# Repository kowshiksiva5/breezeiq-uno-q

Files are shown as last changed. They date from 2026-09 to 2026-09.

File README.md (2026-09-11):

# BreezeIQ

**A room-comfort controller that runs entirely on one Arduino UNO Q.** It does not
hold a thermostat setpoint. It computes how the room *feels* — ISO 7730 PMV, which
counts air velocity, so it knows a fan makes 28 °C feel like 25 °C — and then buys
that feeling with the cheapest watt available.

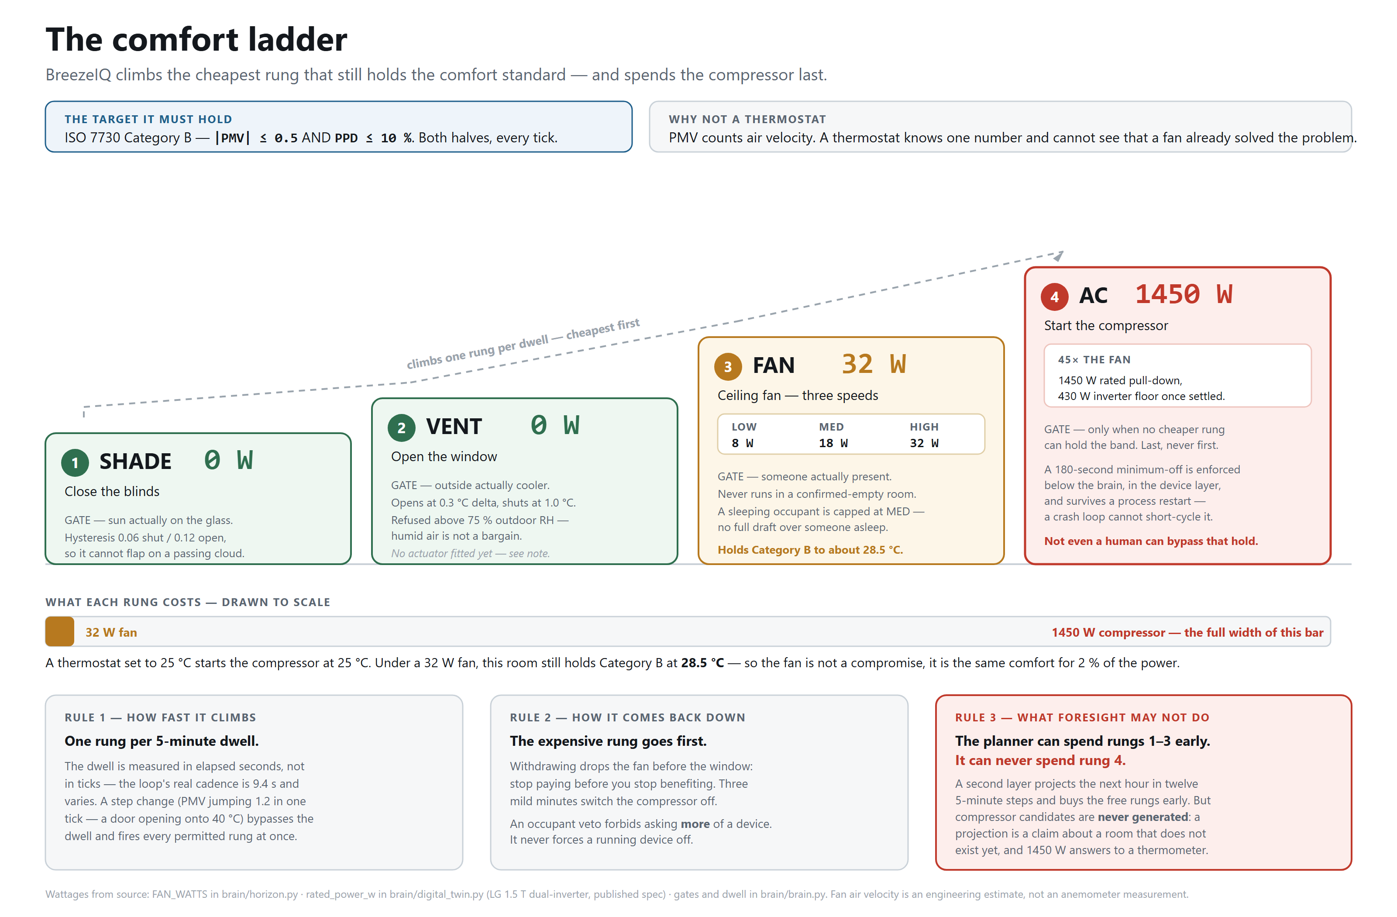
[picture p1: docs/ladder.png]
The comfort ladder: SHADE 0 W, VENT 0 W, FAN 32 W, AC 1450 W, with the gate on each rung


A thermostat set to 25 °C starts a 1450 W compressor at 25 °C. Under a 32 W ceiling
fan the same room still holds ISO Category B comfort at **28.5 °C**. The fan is not a
compromise, it is the same comfort for 2 % of the power — and a setpoint cannot see
that, because air velocity is not one of its inputs.

Each rung fires only if its own gate passes: sun actually on the glass, outdoor air
actually cooler, an occupant actually present. The compressor is spent last, and a
projection is never allowed to start it.

---

## How it works

- **Both halves of the board do real work.** The STM32U585 samples every sensor at
  1 Hz, drives the blinds motor and the LED matrix, and holds a failsafe. The Linux
  MPU runs camera inference, the comfort maths, the policy, SQLite and the web
  console. They talk over Arduino RouterBridge RPC.
- **The STM32 can save the room without Linux.** Ten seconds with no Bridge call and
  the MCU parks the room itself — blinds driven open, failsafe glyph on the matrix —
  armed from boot, re-armed on the next call. A planner that has wedged cannot
  notice it has wedged.
- **One file decides.** `brain/brain.py` is a pure function: reading in, plan out. No
  sockets, no files, no clock. Everything else is transport, so any surprise has
  exactly one suspect.
- **Occupancy is counted on-device and kept nowhere.** A YOLO11s model runs on the
  board's own CPU through ONNX Runtime, fused with the PIR. Frames are counted and
  discarded; one integer is logged. No image ever leaves the board or is stored.
- **An hour-ahead planner spends the free rungs early** — shade and ventilate before
  the heat arrives — but is forbidden from ever starting the compressor, because a
  projection is a claim about a room that does not exist yet.

The board serves its own console over Wi-Fi at `http://breeze.local:8000` — the room
view, a workbench with every raw sensor value, and a log of every command it has
sent and why.

---

## What you need

**₹3 779 (about $45)** of parts if you already own a USB-C hub with power
passthrough, **₹4 629 (about $55)** if you need one too. The board itself came as a
contest award. Prices are Indian street estimates, August 2026.

| Part | Qty | ₹ | What it does |
|---|--:|--:|---|
| **Arduino UNO Q** (4 GB) | 1 | — | Both brains: STM32U585 MCU + Qualcomm Dragonwing Linux MPU |
| **DHT22 / AM2302** | 2 | 250 | Indoor temperature and humidity → the comfort solve. Outdoor → the VENT gate |
| **BH1750** GY-302 lux | 1 | 129 | Sun on the glass → the SHADE gate. I²C, **3.3 V only** |
| **LDR** (GL5528) + 10 kΩ | 1 | 20 | Fallback light sense when lux is unavailable |
| **HC-SR501** PIR | 1 | 90 | Motion → wakes the camera. 3.3 V TTL output, safe |
| **MQ-135** + 10 kΩ/15 kΩ | 1 | 150 | Air-quality trend → evidence for the VENT rung |
| **HLK-LD2410C-P** mmWave radar | 1 | 429 | Presence for a person sitting still. 5 V VCC, 3.3 V logic |
| **UVC webcam**, 720p | 1 | 700 | On-device person count. Must be UVC-class |
| **RS555SF/3162** DC motor | 1 | 50 | Tilts the blinds. 12 V rated, run at 9 V |
| **Bare L298** dual H-bridge IC | 1 | 110 | Drives that motor. *Not* the L298N module — see the traps |
| Motor coupler / bracket | 1 | 40 | Joins the motor to the blind's tilt rod |
| USB-A female breakout | 1 | 60 | Splits the 5 V sensor rail off a spare charger |
| 1000 µF cap + resistor kit | 1 | 50 | Bulk capacitance at the motor, and the two dividers |
| Breadboard 830-pt + jumpers | 1 | 350 | The rig itself |
| 5 mm LED assortment | 1 | 30 | Bench indicators while wiring the driver |
| 9 V supply | 1 | — | Rail C, the motor only |
| USB-C hub **with PD passthrough** | 1 | 850 | The board is USB-C only; this is how the webcam and power coexist |
| White cup + standoff | 1 | 0 | **Radiation shield for the outdoor DHT22 — not optional** |
| Cardboard box + cardstock | 1 | 0 | Scale-model blinds |

Plus, on the network rather than on the board: a **smart ceiling fan** (Atomberg), a
**smart plug** for the AC, and a **smart light**. Any device Home Assistant can reach
works — adding a brand is one file in `act/devices/`.

⚠️ **The USB-C hub must have true PD passthrough.** Without it the board runs off the
hub's own budget and browns out under motor load, dropping the RPC bridge. This is the
one substitution that fails silently.

⚠️ **The radiation shield is not optional.** A DHT22 in direct sun reads 5–10 °C above
true air temperature, which holds the VENT gate false all day and silently disables
free cooling.

---

## Wiring

Arduino UNO Q, **3.3 V logic — no pin on this board is 5 V tolerant.** Pin names are
exactly as silkscreened (no `D` prefix, `~` kept). Direct-wired, no breadboard needed.

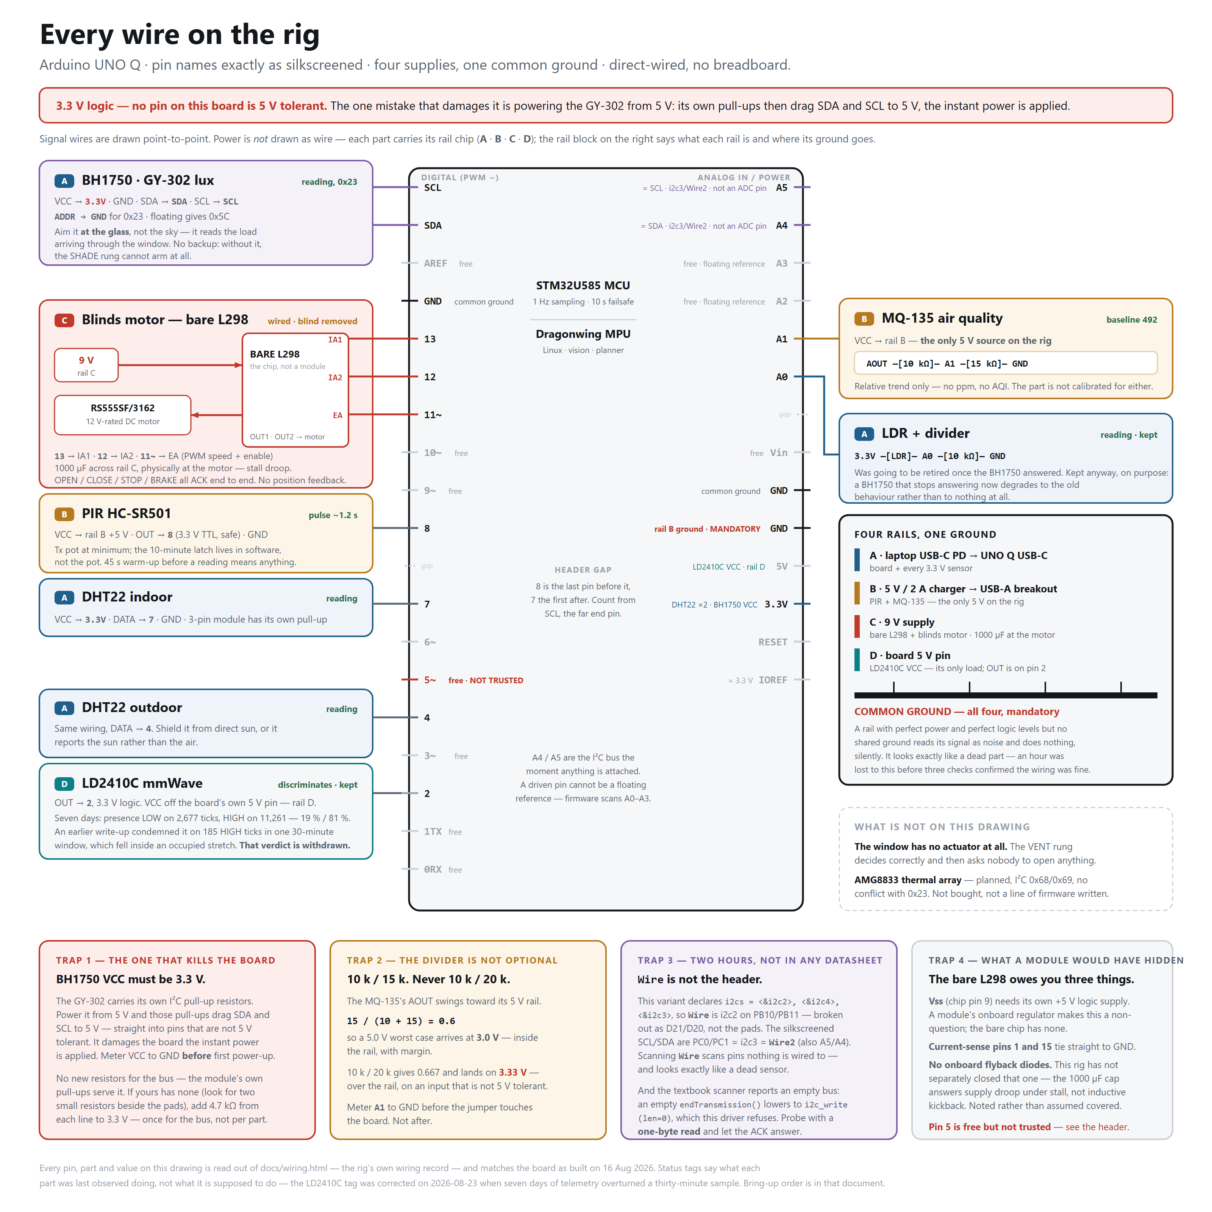
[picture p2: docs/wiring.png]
Every wire on the rig: pin map, four power rails, and the traps


### Every connection

| Part | UNO Q pin | Wiring | Rail |
|---|---|---|---|
| DHT22 indoor | `7` | VCC → `3.3V` · DATA → `7` · GND | A |
| DHT22 outdoor | `4` | VCC → `3.3V` · DATA → `4` · GND. Shield it from the sun | A |
| BH1750 GY-302 | `SDA` `SCL` | VCC → `3.3V` · SDA → `SDA` · SCL → `SCL` · **ADDR → GND** for address `0x23` · GND | A |
| LDR + 10 kΩ | `A0` | `3.3V` —[LDR]— `A0` —[10 kΩ]— GND | A |
| PIR HC-SR501 | `8` | VCC → rail B +5 V · OUT → `8` · GND | B |
| MQ-135 | `A1` | VCC → rail B +5 V · AOUT —[10 kΩ]— `A1` —[15 kΩ]— GND | B |
| LD2410C radar | `2` | VCC → the board's own `5V` pin · OUT → `2` · GND | D |
| Blinds motor, via bare L298 | `13` `12` `11~` | IA1 ← `13` · IA2 ← `12` · EA ← `11~` (PWM speed + enable) · L298 Vs ← 9 V · L298 Vss ← +5 V · sense pins 1 and 15 → GND · motor leads ← OUT1/OUT2 · 1000 µF across rail C at the motor | C |

The fan, the AC and the light are **not** wired to the board. They are reached over
the network. The window has no actuator — the VENT rung decides and asks nobody.

### Four rails, one ground

| Rail | Source | Feeds |
|---|---|---|
| **A** | Laptop or charger USB-C PD → the board's USB-C | The board and every 3.3 V sensor, off its own regulator |
| **B** | 5 V / 2 A charger → USB-A breakout | PIR, MQ-135, and the L298's Vss logic pin. The only 5 V on the rig |
| **C** | 9 V supply | L298 Vs, the blinds motor, the 1000 µF cap |
| **D** | The board's own 5 V pin | The radar only |

**Every rail's ground must land on a board GND pin.** A rail with perfect power and no
shared ground reads its signal as noise and does nothing, silently. It looks exactly
like a dead part — an hour was lost to this before three checks confirmed the wiring
was fine.

### Four traps, all measured on this hardware

1. **BH1750 VCC must be 3.3 V.** The GY-302 carries its own I²C pull-ups, and they sit
   on whatever VCC you feed it. Feed it 5 V and it drags SDA and SCL to 5 V, into pins
   that are not 5 V tolerant, the instant power is applied. Meter VCC to GND *before*
   first power-up.
2. **The MQ-135 divider is not optional, and 10 k / 20 k is wrong.** Its AOUT swings
   toward its 5 V rail. 10 k / 15 k gives 0.6, so a 5.0 V worst case arrives at `A1` as
   3.0 V, inside the rail with margin. 10 k / 20 k gives 0.667 and lands on 3.33 V.
3. **`Wire` is not the header.** On this board the silkscreened SDA/SCL pads are
   PC0/PC1 = i2c3 = **`Wire2`** in firmware. `Wire` is i2c2 on PB10/PB11, broken out as
   D21/D20 — scanning it scans pins nothing is wired to, and looks exactly like a dead
   sensor. Probe with a one-byte read, not an empty `endTransmission()`.
4. **A bare L298 owes you three things** an L298N module would have handled quietly:
   pin 9 `Vss` needs its own +5 V logic supply, current-sense pins 1 and 15 tie
   straight to GND, and there are **no onboard flyback diodes**. The 1000 µF cap
   answers supply droop under stall current; it is not a flyback diode.

### The same rig, drawn for reading

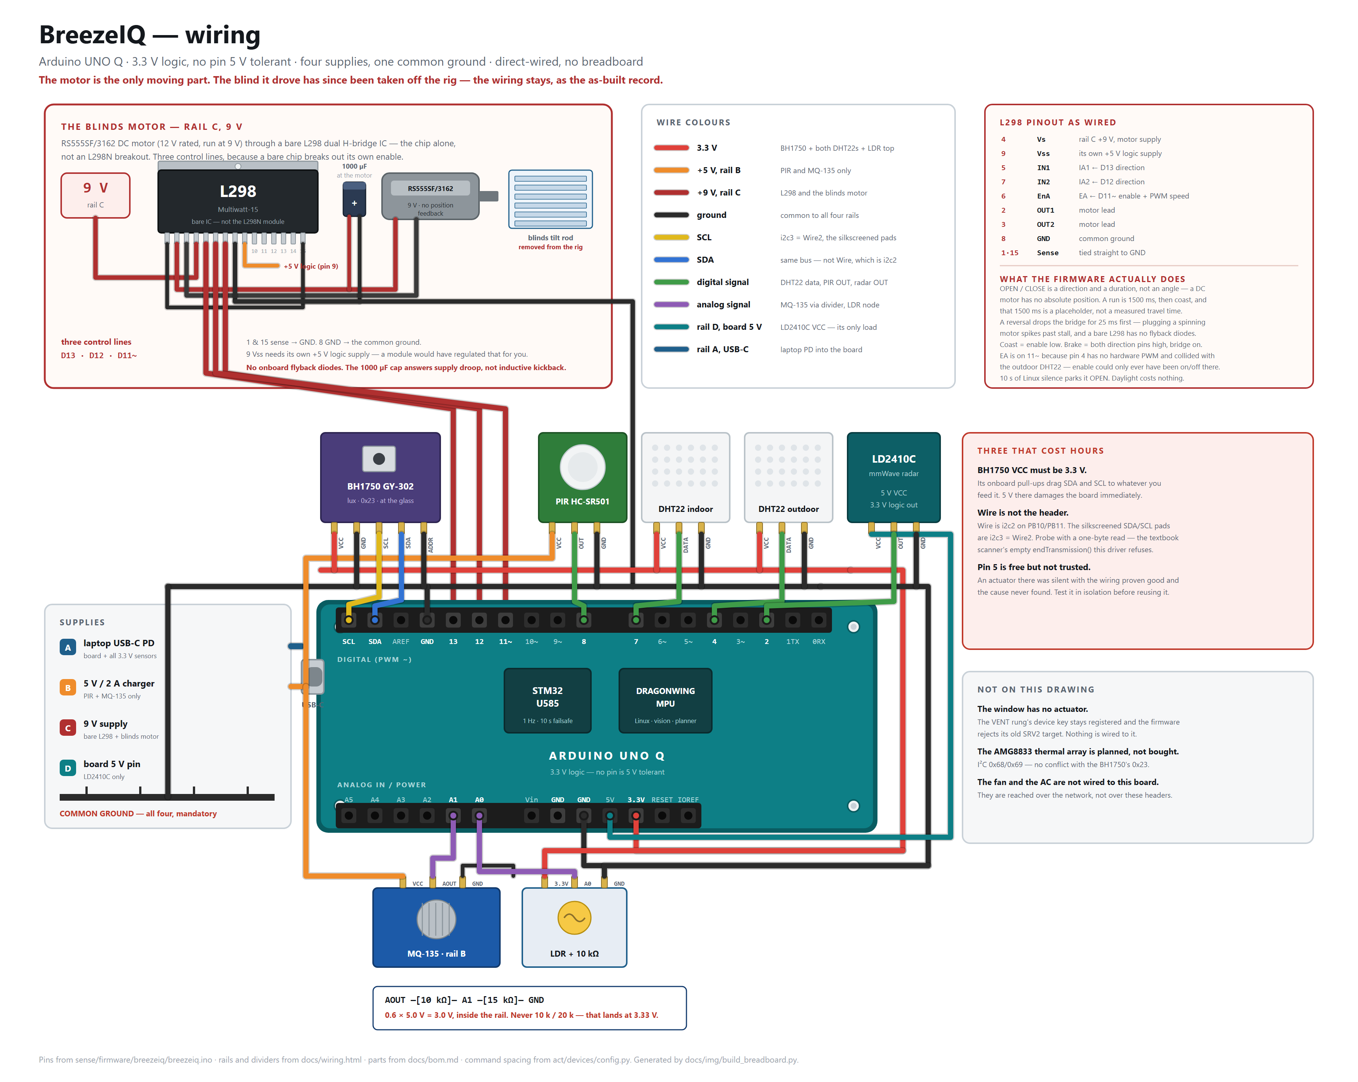
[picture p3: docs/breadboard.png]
Breadboard-style view: every wire drawn to the part it lands on


`docs/breezeiq.fzz` is the same circuit as a **Fritzing** sketch — 15 custom parts,
40 wires, self-contained, no core-parts dependency. Open it once in Fritzing and
re-save before relying on it; it was generated rather than drawn by hand.

### Bring-up order

Sensors first, motor last — brownouts show up there first. Power everything off for
each change. Bring up one sensor at a time and confirm it reads before adding the
next. Wire the motor unloaded, confirm OPEN/CLOSE/STOP, and only then couple it to
the tilt rod.

---

## Build it

### 1 · Try it with no hardware at all

```bash
git clone https://github.com/kowshiksiva5/breezeiq-uno-q.git
cd breezeiq-uno-q
./tools/run.sh setup          # venv + three dependencies
./tools/run.sh demo           # 10 ticks against a simulated room
```

That runs the real control loop — the real comfort solve, the real ladder, the real
telemetry — against a simulated room, and commands nothing. Then:

```bash
./tools/run.sh console        # the web console on http://127.0.0.1:8000
```

### 2 · Flash the STM32 side

```bash
cd firmware
arduino-cli compile --clean --libraries ./libraries -b arduino:zephyr:unoq breezeiq
arduino-cli upload -b arduino:zephyr:unoq -p /dev/cu.usbmodem<yours> breezeiq
```

**Always `--clean`.** Uploads have reported success without flashing on this board;
every sketch prints `BUILD=n` on boot, so check that it says what you just flashed.

### 3 · Put the board on Wi-Fi, then deploy

```bash
./tools/run.sh wifi <your-ssid>     # over USB; the password is asked for, never stored
./tools/run.sh deploy               # pushes the app to the board over SSH
```

`deploy.sh` assembles the App Lab app — the sketch, the Python, the manifest —
stages it on the board, import-checks it there, and only then swaps it in. Press
**Run** in App Lab, or let the boot hook start it after a power cut. The console is
then at `http://breeze.local:8000` from any phone on the same Wi-Fi.

⚠️ **The UNO Q has one USB controller.** A USB-C *data* cable puts the board in
peripheral mode — that is what serves `adb`, and it is also what holds the USB power
regulator disabled, so no USB camera can enumerate. ADB and the camera are mutually
exclusive. Use the cable for first bring-up, then work over Wi-Fi.

### 4 · Connect the real devices

```bash
cp .env.example .env && chmod 600 .env      # then fill it in
```

Home Assistant runs on the board as a protocol adapter and holds no automations of
its own — `act/infra/docker-compose.yml` is the container that runs here. It speaks
Tuya so BreezeIQ never has to. The Atomberg fan is reached through its own API, with
state read free off LAN beacons to stay under the vendor's 100-calls-per-day limit.

**Nothing switches anything real until two gates are set**, both in `.env`:
`BREEZEIQ_LIVE=1` and `BREEZEIQ_SAFETY_VALIDATED=1`. Dry-run is the default on
purpose — a fresh clone must not be able to turn someone's AC on. Set the second gate
only after dry-run output, entity mapping, independent readback, rate limits and the
compressor's minimum-off hold have all been checked.

```bash
./tools/run.sh control --dry-run    # decide against live sensors, touch nothing
./tools/run.sh devices health       # what the device layer can see
./tools/run.sh control --live       # command real devices
```

---

## What is in here

| Path | What |
|---|---|
| `firmware/breezeiq/breezeiq.ino` | The MCU sketch: 1 Hz sampling, Bridge RPC, motor grammar, the 10 s failsafe |
| `firmware/libraries/BreezeIQ/` | One small module per sensor, shared by the sketch |
| `brain/brain.py` | **The only thing that decides anything.** The ladder, as a pure function |
| `brain/comfort.py` | ISO 7730 PMV and PPD |
| `brain/horizon.py` | The hour-ahead planner |
| `brain/digital_twin.py` | The AC response model |
| `brain/loop.py` | Read → decide → command → log. Translates; decides nothing |
| `brain/telemetry.py` | Every tick to SQLite |
| `brain/dashboard.py` · `console.py` | The API, and the pages rendered over it. Stdlib only |
| `sense/reader/` | Bridge RPC, serial and simulated sensor sources behind one interface |
| `sense/vision/` | On-device person counting, and the policy for when to look |
| `act/devices/` | Home Assistant, Atomberg, the board's own motor, simulated |
| `app/` | App Lab packaging |
| `tools/` | `run.sh` for everything local, `deploy.sh` for the board |
| `docs/` | The wiring drawings and the Fritzing sketch |

Adding a device brand is one file: subclass `DeviceBackend`, register it, done.
Nothing upstream changes — the Atomberg fan proved it, and the ladder never learned a
word of its protocol.

---

## Known limits, stated plainly

- **The window has no actuator.** The VENT rung decides correctly and then asks
  nobody to open anything. Three of the four rungs move real hardware.
- **The "weather" is the board's own outdoor sensor**, not a fetched forecast. That
  is deliberate — the appliance has to work with no internet — but it means the
  horizon is a projection from local physics, not a meteorological one.
- **The energy comparisons are simulated**, from the repository's own room model,
  and are labelled that way wherever they appear.
- **The console trusts its LAN.** There is no login. Keep the board behind your
  router and do not expose port 8000 to the internet.

---

## License

MIT — see [`LICENSE`](LICENSE). Built on an Arduino UNO Q supplied as a contest award
for *Invent the Future with Arduino UNO Q & App Lab* (Hackster.io).

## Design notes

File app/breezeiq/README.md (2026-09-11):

# BreezeIQ — the App Lab app

Passive-first room comfort on the Arduino UNO Q. Both halves of the board are used:

- **STM32** (`sketch/`) — sensors, the blinds motor, the LED matrix, and a failsafe:
  10 s without a Bridge call and the MCU drives the blinds open at full speed and
  lights a matrix glyph on its own, re-arming when calls resume.
- **Linux MPU** (`python/`) — PMV comfort maths, the passive-first ladder, device
  control, and the console on `:8000`.

## Run

Press **Run** in App Lab. Then open `http://<board-ip>:8000` from any phone on the
same Wi-Fi. `tools/deploy.sh` also installs a boot hook, so the app comes back on
its own after a power cut with no laptop present.

Dry-run by default. Real commands require both `BREEZEIQ_LIVE=1` and
`BREEZEIQ_SAFETY_VALIDATED=1` in the board's own `.env`, which `deploy.sh` carries
forward and never uploads. Credentials live only there:

    HA_URL, HA_TOKEN                        Tuya devices via Home Assistant
    ATOMBERG_API_KEY, ATOMBERG_REFRESH_TOKEN, ATOMBERG_FAN_ID

Home Assistant runs at `http://127.0.0.1:8123` on the board and holds device
integrations only. BreezeIQ owns policy and manual-override authority.

## The one rule

`brain.py` is the only thing that makes a comfort decision, and it is a pure
function. Everything else — sensors, devices, dashboard — is transport. Keep it that
way and any surprise has exactly one suspect.

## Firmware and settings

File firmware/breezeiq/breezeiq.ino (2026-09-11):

/*
 * BreezeIQ wiring verifier. One question per input: is it connected, and if
 * not, what is wrong. Emits a key=value line per second for the dashboard and
 * lights one matrix column per channel that produced a usable reading:
 *
 *   col 0 = DHT22 indoor   col 1 = DHT22 outdoor   col 2 = LDR
 *   col 3 = PIR            col 4 = MQ-135
 *
 * It also holds the one promise Linux cannot keep for itself: if the Linux
 * side stops calling over the Bridge, this sketch parks the blinds motor in
 * its safe position on its own. See the failsafe section below.
 *
 * Four RPCs are exposed: breezeiq/read (telemetry), breezeiq/cmd (motor and
 * the display), breezeiq/display (the display alone), and breezeiq/radar_tune
 * (a bench-only hex relay onto the radar's serial port; the deployed loop never
 * calls it). Every one of them is also proof Linux is alive, so every one of
 * them re-arms the failsafe -- as does every complete serial command line.
 */

#include <DHT.h>
#include <Wire.h>
#include "Arduino_LED_Matrix.h"
#include "Arduino_RouterBridge.h"

// Adafruit DHT 1.4.7 calls these Arduino API functions from its timing guard,
// but Arduino UNO Q Zephyr core 0.90.0 declares them without exporting an
// implementation to App Lab sketches. Interrupt masking also stalls the UNO Q
// bridge transport. Keep the library's proven pulse decoder and map its guard
// to Zephyr's scheduler lock. This prevents thread preemption during the pulse
// train while leaving RouterBridge and other hardware interrupts operational.
#if defined(ARDUINO_ARCH_ZEPHYR)
extern "C" void k_sched_lock(void);
extern "C" void k_sched_unlock(void);
void noInterrupts() { k_sched_lock(); }
void interrupts() { k_sched_unlock(); }
#endif

constexpr int PIN_DHT_INDOOR  = 7;    // "7"
constexpr int PIN_DHT_OUTDOOR = 4;    // "4"
constexpr int PIN_PIR         = 8;    // "8"
constexpr int PIN_LDR         = A0;   // "A0"
constexpr int PIN_MQ135       = A1;   // "A1"
constexpr int PIN_RADAR       = 2;    // "2"  LD2410C OUT, 3.3 V logic -- back to its physical
                                       // wiring. The D2->D13 move was a diagnostic (isolating
                                       // pin vs. sensor); the sensor itself is the dead part
                                       // either way -- see the README's wiring table. Kept wired and read
                                       // rather than removed: it's still physically on the rig.

// BH1750 on the I²C header pins, which on this board means Wire2 and not Wire.
// The variant declares i2cs = <&i2c2>, <&i2c4>, <&i2c3>, so Wire is i2c2 on
// PB10/PB11 (broken out as D21/D20), Wire1 is i2c4 (the camera's bus, left
// alone), and only Wire2 is i2c3 on PC0/PC1 — the pads silkscreened SCL and
// SDA, which are also A5 and A4. Scanning Wire finds an empty bus and looks
// exactly like a dead sensor, which cost an evening; the bus is named once
// here so it cannot be assumed again.
//
// Register-level because the whole part is three bytes: a mode, a wait, and a
// big-endian count that is lux times 1.2. Both addresses are probed at run
// time rather than one being assumed — see bh1750Begin().
// All three, because "which bus" and "is it wired" are different questions and
// only a scan of every bus separates them. Wire is i2c2 (PB10/PB11 = D21/D20),
// Wire1 is i2c4, Wire2 is i2c3 (PC0/PC1 = the SCL/SDA pads, also A5/A4).
arduino::ZephyrI2C *const I2C_BUSES[] = {&Wire, &Wire1, &Wire2};
constexpr int I2C_BUS_COUNT = sizeof(I2C_BUSES) / sizeof(I2C_BUSES[0]);
constexpr uint8_t  BH1750_ADDR_LOW   = 0x23;   // ADDR tied low / floating
constexpr uint8_t  BH1750_ADDR_HIGH  = 0x5C;   // ADDR tied to 3.3 V
constexpr uint8_t  BH1750_CONT_HIGH = 0x10;   // continuous, 1 lx, ~120 ms
constexpr float    BH1750_DIVISOR   = 1.2f;
constexpr float    BH1750_MAX_LUX   = 54612.0f;

constexpr int ADC_MAX = 4095;         // 12-bit
// How far off either rail a count has to sit before it is worth anything. The
// host's reader uses the same 15; keep them equal or the two disagree about
// which channels are alive.
constexpr int ADC_RAIL_MARGIN = 15;

constexpr unsigned long SAMPLE_PERIOD_MS = 1000;
unsigned long nextSampleAt = 0;

// ── live tuning state ───────────────────────────────────────────────────
// hwcheck feeds the dashboard, so the tuning numbers you would otherwise get
// from t1..t5 are computed here too. Cover the LDR / wave at the PIR and the
// constants appear on the page — no reflashing between tune and observe.
int  ldrMin = ADC_MAX, ldrMax = 0;         // -> LDR_RAW_DARK / LDR_RAW_SUN
int  dhtOk = 0, dhtTry = 0;                // DHT read success rate
float dhtMinC = 1e9, dhtMaxC = -1e9;       // DHT noise band when idle
unsigned long pirEvents = 0, pirHighSince = 0, pirLastPulse = 0;
bool  pirPrev = false;
float mqR0k = NAN;                         // clean-air baseline

// Calibrated 2026-08-09 against a trusted 25.0 C room reference after the
// firmware restart. Twelve live samples averaged 27.06 C indoors and 27.00 C
// outdoors. Keep the raw values in telemetry as proof of the sensor output.
constexpr float TEMP_REFERENCE_C  = 25.0f;
constexpr float TEMP_OFFSET_IN_C  = -2.1f;
constexpr float TEMP_OFFSET_OUT_C = -2.0f;

DHT dhtIndoor(PIN_DHT_INDOOR, DHT22);
DHT dhtOutdoor(PIN_DHT_OUTDOOR, DHT22);
ArduinoLEDMatrix matrix;
uint8_t frame[8 * 13];
String latestSnapshot = "";

enum Status : uint8_t { ST_OK, ST_NO_RESPONSE };

// Use the underlying byte in this public signature because App Lab's Arduino
// preprocessor injects function prototypes above sketch-defined enum types.
const char *statusName(uint8_t s) {
  switch (s) {
    case ST_OK:          return "OK";
    case ST_NO_RESPONSE: return "NO_RESPONSE";
    default:             return "NO_RESPONSE";
  }
}

// No connectivity heuristic here any more. Three of them were tried (internal
// pull-up/pull-down, absolute level, single-HIGH latch) and a floating CMOS
// input defeated all three — the old code reported a confident OK on a pin with
// nothing attached, and the dashboard turned that into a fake air-quality
// reading. The board now reports the raw count and nothing else; deciding what
// is connected is done host-side by comparing against A0, A2 and A3, which are
// known to have nothing on them. A4/A5 used to be in that set and no longer
// qualify: they are the I²C bus now, and a driven pin is not a reference.
void readAnalogStable(int pin, int &average, int &span) {
  // Discard the first conversion after switching ADC channels, then measure a
  // short burst. A driven divider stays tight; a loose/floating node wanders.
  (void)analogRead(pin);
  delayMicroseconds(200);
  long total = 0;
  int low = ADC_MAX, high = 0;
  for (int i = 0; i < 8; i++) {
    int value = analogRead(pin);
    total += value;
    if (value < low) low = value;
    if (value > high) high = value;
    delayMicroseconds(100);
  }
  average = (int)(total / 8);
  span = high - low;
}

// The PIR reports its raw level. Whether that level means "a PIR is attached"
// is not something this board can decide — see the note above.
bool readPir(int pin) {
  pinMode(pin, INPUT);
  return digitalRead(pin) == HIGH;
}

// The radar's OUT is a level, exactly like the PIR's, and carries the same
// caveat: this board reports what the pin says and does not claim a part is
// attached. What differs is upstream — OUT stays HIGH for a person sitting
// still, which is the whole reason it is here beside a PIR that will not.
//
// The level alone is not enough to tell a working radar from a dead one: a
// stuck pin and a genuinely occupied room read identically at any single
// instant. What separates them is TIME — a live sensor changes its mind
// eventually, a dead one never does. So the two figures below ride along
// with the level, and they are what actually diagnosed this part: edges
// counts transitions since boot, held_ms is how long the current level has
// stood. Zero edges over hours is not presence, it is a fault.
unsigned long radarEdges = 0;
unsigned long radarHeldSince = 0;
int radarLastLevel = -1;

bool readRadar(int pin) {
  pinMode(pin, INPUT);
  bool level = digitalRead(pin) == HIGH;
  if (radarLastLevel != (int)level) {
    if (radarLastLevel != -1) radarEdges++;   // boot is not an edge
    radarLastLevel = (int)level;
    radarHeldSince = millis();
  }
  return level;
}

// Which address answered, or 0. Kept as state because the useful question is
// not "did this read fail" but "is the part on the bus at all", and those need
// different fixes — a swapped SDA/SCL pair versus a floating ADDR pin.
uint8_t bh1750Addr = 0;
int     bh1750Bus  = -1;
int     i2cDevices = -1;
int     busDevices[3] = {-1, -1, -1};
bool    sdaPullup = false, sclPullup = false;   // boot-time only, see setup()
int     sdaLevel = -1, sclLevel = -1;           // the same pins via the ADC

// Probes with a one-byte read, not an empty write. endTransmission() with
// nothing buffered lowers to i2c_write(len=0), which this STM32 driver refuses
// outright — so the textbook Arduino scan reports an empty bus whatever is on
// it. A read puts a real START and address on the wire and the ACK is the
// answer. Non-destructive: nothing is written to a part we have not identified.
bool i2cPresent(arduino::ZephyrI2C *bus, uint8_t addr) {
  return bus->requestFrom((int)addr, 1) == 1;
}

// Try both BH1750 addresses rather than only the wired one. ADDR floating
// instead of tied is the single most likely wiring slip on this part, and it
// presents as total silence at 0x23 while the sensor sits happily at 0x5C.
// Re-runs while unfound, so plugging it in does not need a reboot.
void bh1750Begin() {
  bh1750Addr = 0;
  bh1750Bus = -1;
  for (int b = 0; b < I2C_BUS_COUNT && !bh1750Addr; b++) {
    if (i2cPresent(I2C_BUSES[b], BH1750_ADDR_LOW))       bh1750Addr = BH1750_ADDR_LOW;
    else if (i2cPresent(I2C_BUSES[b], BH1750_ADDR_HIGH)) bh1750Addr = BH1750_ADDR_HIGH;
    if (bh1750Addr) bh1750Bus = b;
  }
  if (bh1750Bus < 0) return;
  // A one-byte write, which is a real transfer and therefore actually lands.
  arduino::ZephyrI2C *bus = I2C_BUSES[bh1750Bus];
  bus->beginTransmission(bh1750Addr);
  bus->write(BH1750_CONT_HIGH);
  if (bus->endTransmission() != 0) { bh1750Addr = 0; bh1750Bus = -1; }
}

// Counts everything that ACKs. Distinguishes "the bus is dead" from "the bus
// works and this part is not on it" — one is wiring to the board, the other is
// wiring to the module, and guessing between them wastes an evening.
int i2cScan() {
  int found = 0;
  for (int b = 0; b < I2C_BUS_COUNT; b++) {
    busDevices[b] = 0;
    for (uint8_t addr = 0x08; addr < 0x78; addr++)
      if (i2cPresent(I2C_BUSES[b], addr)) busDevices[b]++;
    found += busDevices[b];
  }
  return found;
}

// Negative means "no answer", which is a different fact from 0 lux and has to
// survive as one — a dark room and an absent sensor must never serialise the
// same. An I²C part either ACKs or it does not, so unlike the ADC channels
// this one can honestly report its own presence.
//
// Every OTHER channel on this board is a burst average — readAnalogStable()
// takes 8 samples specifically because "a driven divider stays tight; a
// loose/floating node wanders." The BH1750's first live minutes proved the
// same is true of it: lux swung 24 to 127 tick to tick on a room the LDR saw
// as perfectly steady throughout, which is enough on its own to flap the fused
// dark/normal verdict.
//
// Smoothed across TICKS rather than as a burst inside one. A burst needs the
// part's ~120 ms conversion time between samples to get fresh conversions
// rather than the same register three times, and spending 60+ ms blocked here
// would starve serviceIo(), which has to keep pumping the motor's run timer
// and the command channel — the sensor read sits mid-tick, where a timed
// drive may be in progress. The
// sampler already runs at 1 Hz, so a short running mean over consecutive
// ticks costs nothing and blocks nobody.
//
// A failed transfer resets the window instead of averaging across the gap: a
// part that dropped off the bus and came back is not the same reading it was
// before, and a missing sensor must stay unambiguous.
constexpr int BH1750_WINDOW = 4;
float bh1750Recent[BH1750_WINDOW];
int   bh1750Count = 0;

float readBh1750() {
  if (!bh1750Addr || bh1750Bus < 0) { bh1750Count = 0; return -1.0f; }
  arduino::ZephyrI2C *bus = I2C_BUSES[bh1750Bus];
  if (bus->requestFrom((int)bh1750Addr, 2) != 2) {
    bh1750Addr = 0; bh1750Count = 0; return -1.0f;
  }
  uint16_t raw = ((uint16_t)bus->read() << 8) | bus->read();
  float lux = raw / BH1750_DIVISOR;
  if (lux > BH1750_MAX_LUX) lux = BH1750_MAX_LUX;

  if (bh1750Count < BH1750_WINDOW) {
    bh1750Recent[bh1750Count++] = lux;
  } else {
    for (int i = 1; i < BH1750_WINDOW; i++) bh1750Recent[i - 1] = bh1750Recent[i];
    bh1750Recent[BH1750_WINDOW - 1] = lux;
  }
  float total = 0;
  for (int i = 0; i < bh1750Count; i++) total += bh1750Recent[i];
  return total / bh1750Count;
}

// Three tenants on one 8x13 panel, and they do not overlap by construction:
//
//   rows 1-6, x = 1,3,5,7,9   five sensor-health columns (this board's own)
//   row  7,   x = 0..8        people count, one pixel each (from Linux)
//   rows 0-7, x = 10          occupancy mode glyph        (from Linux)
//   rows 0-7, x = 11..12      failsafe                    (this board's own)
constexpr int MATRIX_COLS = 13;
constexpr int MATRIX_ROWS = 8;
constexpr int FAILSAFE_GLYPH_COL = 11;   // 11..12, clear of every other tenant
constexpr int OCCUPANCY_GLYPH_COL = 10;
constexpr int PEOPLE_BAR_ROW = 7;
constexpr int PEOPLE_MAX = 9;
constexpr int OCCUPANCY_MODES = 4;

// One bit per row, LSB = row 0. Four shapes nobody has to decode: nothing, a
// dot, a solid column, a dashed column.
constexpr uint8_t OCCUPANCY_GLYPH[OCCUPANCY_MODES] = {
  0x00,   // 0 EMPTY    — a dark column, because nobody is here
  0x18,   // 1 OCCUPIED — a dot at the middle
  0xFF,   // 2 CROWDED  — solid
  0x55,   // 3 ASLEEP   — dashed
};

bool channelOk[5] = {false, false, false, false, false};
bool failsafeActive = false;
int  occupancyMode = -1;      // -1 = Linux has not said yet, so nothing drawn
int  peopleCount = 0;
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
void loop() {
  // The library rate-limits internally (a DHT22 samples at 0.5 Hz) and returns
  // its cached frame in between, so calling once a second is fine.
  float tInRaw  = dhtIndoor.readTemperature(),  hIn  = dhtIndoor.readHumidity();
  float tOutRaw = dhtOutdoor.readTemperature(), hOut = dhtOutdoor.readHumidity();

  Status sIn  = isnan(tInRaw)  ? ST_NO_RESPONSE : ST_OK;
  Status sOut = isnan(tOutRaw) ? ST_NO_RESPONSE : ST_OK;
  float tIn  = isnan(tInRaw)  ? tInRaw  : tInRaw  + TEMP_OFFSET_IN_C;
  float tOut = isnan(tOutRaw) ? tOutRaw : tOutRaw + TEMP_OFFSET_OUT_C;

  // A4 and A5 are the I²C bus. Sampling them as ADC channels was harmless
  // while nothing was attached — they were the reference pins the host uses to
  // recognise a floating input — but a driven bus reads like a live sensor and
  // would turn that reference into a lie. A0 replaces them once the LDR goes.
  const int adcPins[4] = {A0, A1, A2, A3};
  int adcValue[4], adcSpan[4];
  for (int i = 0; i < 4; i++)
    readAnalogStable(adcPins[i], adcValue[i], adcSpan[i]);

  int   ldr    = adcValue[0];
  int   mq     = adcValue[1];
  bool  motion = readPir(PIN_PIR);
  bool  radar  = readRadar(PIN_RADAR);
  if (!bh1750Addr) { i2cDevices = i2cScan(); bh1750Begin(); }
  float lux    = readBh1750();

  // ── tuning accumulators ───────────────────────────────────────────────
  // These are what t1..t5 would print. Computed here so you can tune while
  // watching the dashboard, instead of reflashing between tune and observe.
  dhtTry++;
  if (!isnan(tIn)) {
    dhtOk++;
    if (tIn < dhtMinC) dhtMinC = tIn;
    if (tIn > dhtMaxC) dhtMaxC = tIn;
  }
  // Only track the LDR range once the pin is genuinely driven. A floating or
  // half-built divider would otherwise pin dark at 0 and sun at 4095 and the
  // captured constants would be pure noise.
  if (ldr > ADC_RAIL_MARGIN && ldr < ADC_MAX - ADC_RAIL_MARGIN
      && adcSpan[0] < 300) {
    if (ldr < ldrMin) ldrMin = ldr;
    if (ldr > ldrMax) ldrMax = ldr;
  }
  if (motion && !pirPrev) { pirHighSince = millis(); pirEvents++; }
  if (!motion && pirPrev && pirHighSince) pirLastPulse = millis() - pirHighSince;
  pirPrev = motion;

  // MQ baseline = cleanest air seen = highest sensor resistance.
  if (mq > ADC_RAIL_MARGIN && mq < ADC_MAX - ADC_RAIL_MARGIN) {
    float vOut = ((mq / 4095.0f) * 3.3f) / 0.6f;
    vOut = vOut > 4.99f ? 4.99f : (vOut < 0.01f ? 0.01f : vOut);
    float rs = (5.0f - vOut) / vOut * 10.0f;
    if (isnan(mqR0k) || rs > mqR0k) mqR0k = rs;
  }

  // A lit column means "this channel produced a usable reading just now", and
  // nothing stronger. The DHTs prove themselves by answering; the PIR shows
  // its live level; the two ADC channels light when they sit off both rails,
  // which is the strongest honest statement this board can make about an
  // analogue pin — see the note above readAnalogStable() for why "connected"
  // is a host-side verdict. An unlit LDR column is real information, not a
  // placeholder: it means that pin is pinned to a rail right now.
  channelOk[0] = sIn == ST_OK;
  channelOk[1] = sOut == ST_OK;
  channelOk[2] = ldr > ADC_RAIL_MARGIN && ldr < ADC_MAX - ADC_RAIL_MARGIN;
  channelOk[3] = motion;
  channelOk[4] = mq > ADC_RAIL_MARGIN && mq < ADC_MAX - ADC_RAIL_MARGIN;
  drawMatrix();

  // Rails cannot be measured from the MCU, only inferred from a sensor that
  // answers. A DHT that replies proves its own 3.3 V. The analogue heuristics
  // cannot prove anything, so they are not allowed to claim a rail.
  const char *rail33 = (sIn == ST_OK || sOut == ST_OK) ? "PROVEN" : "UNPROVEN";
  const char *rail5  = "UNPROVEN";   // nothing on rail B can prove itself to the MCU

  latestSnapshot = "HW in_c=" + String(isnan(tIn) ? 0.0f : tIn, 1)
    + " in_rh=" + String(isnan(hIn) ? 0.0f : hIn, 1)
    + " out_c=" + String(isnan(tOut) ? 0.0f : tOut, 1)
    + " out_rh=" + String(isnan(hOut) ? 0.0f : hOut, 1)
    // The uncalibrated readings, beside the corrected ones rather than
    // instead of them. TEMP_OFFSET_*_C is applied on this board, so without
    // these the offset is unrecoverable downstream and telemetry's own promise
    // — raw values stay beside calibrated ones so a future recalibration does
    // not have to rewrite history — is quietly broken for the two channels the
    // whole comfort calculation rests on.
    + " in_raw_c=" + String(isnan(tInRaw) ? 0.0f : tInRaw, 1)
    + " out_raw_c=" + String(isnan(tOutRaw) ? 0.0f : tOutRaw, 1)
    + " ldr=" + String(ldr)
    + " mq=" + String(mq)
    + " pir=" + String(motion ? 1 : 0)
    + " s_in=" + String(statusName(sIn))
    + " s_out=" + String(statusName(sOut))
    + " ldr_min=" + String(ldrMin == ADC_MAX ? -1 : ldrMin)
    + " ldr_max=" + String(ldrMax)
    // Both readers parse an HW line as loose key=value pairs and ignore keys
    // they do not know, so these ride the existing frame rather than a second
    // channel. The flag is the live state; the counter is what survives the
    // gap, because a Linux side that was silent through the episode is by
    // definition not reading while the flag is up.
    + " failsafe=" + String(failsafeActive ? 1 : 0)
    + " failsafe_n=" + String(failsafeEpisodes)
    // lux=-1 is "the part did not ACK", not darkness. The reader keeps that
    // distinction; it is the difference between a missing sensor and a night.
    + " lux=" + String(lux, 1)
    + " lux_addr=" + String(bh1750Addr)
    + " i2c_n=" + String(i2cDevices)
    + " i2c_b0=" + String(busDevices[0])
    + " i2c_b1=" + String(busDevices[1])
    + " i2c_b2=" + String(busDevices[2])
    + " lux_bus=" + String(bh1750Bus)
    + " sda_pu=" + String(sdaPullup ? 1 : 0)
    + " scl_pu=" + String(sclPullup ? 1 : 0)
    + " sda_lvl=" + String(sdaLevel)
    + " scl_lvl=" + String(sclLevel)
    + " radar=" + String(radar ? 1 : 0)
    // The two figures that tell a working radar from a stuck pin. See readRadar().
    + " radar_edges=" + String(radarEdges)
    + " radar_held_ms=" + String(millis() - radarHeldSince)
    // Motor state, so the Workbench shows what the actuator was last told
    // rather than what somebody hoped it did. No feedback wire exists.
    + " motor_dir=" + String(blindsMotor.dir)
    + " motor_speed=" + String(blindsMotor.speed)
    // How much of the commanded window is left — ground truth for the bench
    // panel's countdown, which otherwise runs on the browser's own clock.
    + " motor_left_ms=" + String(blindsMotor.dir == 0 ? 0
        : (millis() - blindsMotor.startedAt >= blindsMotorRunMs ? 0
           : blindsMotorRunMs - (millis() - blindsMotor.startedAt)))
    + " fw_build=" + String(FW_BUILD);
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

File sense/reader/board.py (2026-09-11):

"""STM32 over USB serial — the rig as it stands today.

The MCU emits one `HW key=value ...` line per second. This parses it. When the
Bridge RPC replaces the cable, only this file is rewritten; SensorFrame and
everything above it stay untouched. That is the point of the seam.
"""
from __future__ import annotations

import glob
import threading
import time
from collections import deque
from typing import Optional

from .base import (SensorFrame, SensorSource, decode_flag, decode_lux,
                   register_source)

try:
    import serial                                  # pyserial
except ImportError:                                # board has no pyserial; Bridge later
    serial = None

BAUD = 115200
STALE_AFTER_S = 8.0
ADC_MAX = 4095
ADC_RAIL_MARGIN = 15
LDR_RAIL_WINDOW_S = 12.0


def find_port() -> Optional[str]:
    ports = sorted(glob.glob("/dev/cu.usbmodem*") + glob.glob("/dev/ttyACM*"))
    return ports[0] if ports else None


@register_source("stm32-serial")
class SerialSensorSource(SensorSource):
    """Reads in a background thread so a slow or absent board never blocks the
    control loop — the loop takes whatever the last line said."""

    def __init__(self, port: Optional[str] = None, **kwargs):
        super().__init__(**kwargs)
        self.port = port or find_port()
        self._lock = threading.Lock()
        self._fields: dict = {}
        self._at = 0.0
        self._ldr_recent = deque(maxlen=30)
        self._conn = None
        self._error: Optional[str] = None

    def start(self) -> "SerialSensorSource":
        threading.Thread(target=self._reader, daemon=True).start()
        return self

    def _reader(self) -> None:
        while True:
            if serial is None:
                self._error = "pyserial not installed"
                time.sleep(10)
                continue
            try:
                self.port = self.port or find_port()
                if not self.port:
                    self._error = "no board found"
                    time.sleep(3)
                    continue
                with serial.Serial(self.port, BAUD, timeout=3) as conn:
                    self._conn, self._error = conn, None
                    while True:
                        line = conn.readline().decode(errors="replace").strip()
                        if line.startswith("HW "):
                            self._ingest(line)
            except Exception as exc:
                self._error = f"{type(exc).__name__}: {exc}"
                self._conn, self.port = None, None
                time.sleep(3)

    def _ingest(self, line: str) -> None:
        fields = {}
        for token in line.split()[1:]:
            if "=" in token:
                k, _, v = token.partition("=")
                fields[k] = v
        now = time.time()
        with self._lock:
            self._fields, self._at = fields, now
            try:
                self._ldr_recent.append((now, int(fields["ldr"])))
            except (KeyError, ValueError):
                pass

    def send(self, ch: str) -> bool:
        """Actuator commands share the reader's connection — a second handle
        would race it for incoming bytes."""
        conn = self._conn
        if conn is None:
            return False
        try:
            conn.write(ch.encode()[:1])
            conn.flush()
            return True
        except Exception:
            return False

    def _read_raw(self) -> SensorFrame:
        with self._lock:
            fields, at, err = dict(self._fields), self._at, self._error
            ldr_recent = list(self._ldr_recent)
        if not fields:
            return SensorFrame(fault=err or "no data from the board yet")
        if time.time() - at > STALE_AFTER_S:
            return SensorFrame(fault=f"board silent for {int(time.time()-at)}s")

        def num(key, cast=float):
            try:
                return cast(fields[key])
            except (KeyError, ValueError):
                return None

        light = num("ldr", int)
        dark, sun = num("ldr_min", int), num("ldr_max", int)
        solar = None
        # Only report a solar index once the calibration span is real; a
        # half-built divider would otherwise produce confident nonsense.
        recent = [value for seen_at, value in ldr_recent
                  if at - seen_at <= LDR_RAIL_WINDOW_S]
        rail_to_rail = (any(value <= ADC_RAIL_MARGIN for value in recent)
                        and any(value >= ADC_MAX - ADC_RAIL_MARGIN
                                for value in recent))
        current_driven = (light is not None
                          and ADC_RAIL_MARGIN < light < ADC_MAX - ADC_RAIL_MARGIN)
        if (None not in (light, dark, sun) and sun - dark > 500
                and current_driven and not rail_to_rail):
            solar = max(0.0, min(1.0, (light - dark) / (sun - dark)))
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
